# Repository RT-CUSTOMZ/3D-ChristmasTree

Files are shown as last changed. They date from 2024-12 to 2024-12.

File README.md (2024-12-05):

A 3D Christmas Tree based on WLED
USE WS2812 or SK6812 LEDs in combination with an WaveShare ESP32-S3 Mini Development Board
https://eckstein-shop.de/WaveShare-ESP32-S3-Mini-Development-Board-ESP32-S3FH4R2-240MHz-24GHz-Wi-Fi-Bluetooth-5

Board thickness 1.6 mm
Can use HASL or chem. Gold plating for silver or gold colored christmas ornaments

Populate boards accoring to silk screen prints
Connectors belong to the side with the silk screen print
Check LED function before assambling the tree
Slide the two tree PCBs into each other and use symbols on PCBs to ensure correct orientation
Afterwards use the same symbols as solder joints to give the tree more stability
Lastely connect the brain PCB to the tree assembly

As of end 2024 the WLED software is marked experimental for ESP32-S3 chipset, therefore install WLED via 
https://wled-install.github.io/
and select an ESP32-S3 version (4 MB Flash).

After installation open WLED controls and load Presets and Configuration from Backup Files

Short button press - On / Off
Long button press - Toggle presets

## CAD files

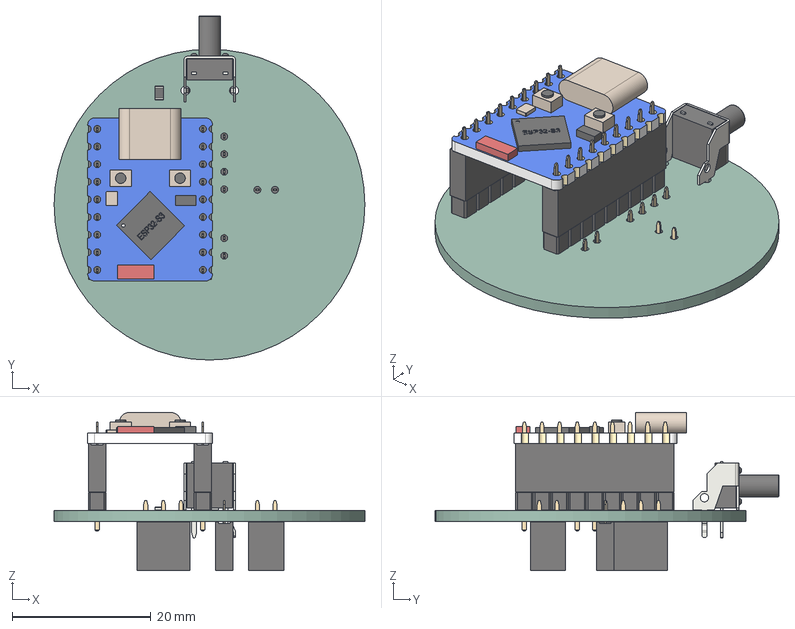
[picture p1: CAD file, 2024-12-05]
ChristmasTreeBrain/ChristmasTreeBrain/ChristmasTreeBrain.step
44.8 x 49.6 x 22.8 mm
SW_Tactile_SPST_Angled_PTS645Vx83-2LFS
ESP32-S3 Zero
PinHeader_1x09_P254mm_Vertical x 2
PinSocket_1x09_P254mm_Vertical x 2
R_0805_2012Metric
PinSocket_1x04_P254mm_Vertical
PinSocket_1x03_P254mm_Vertical
PinSocket_1x02_P254mm_Vertical x 2
ChristmasTreeBrain_PCB

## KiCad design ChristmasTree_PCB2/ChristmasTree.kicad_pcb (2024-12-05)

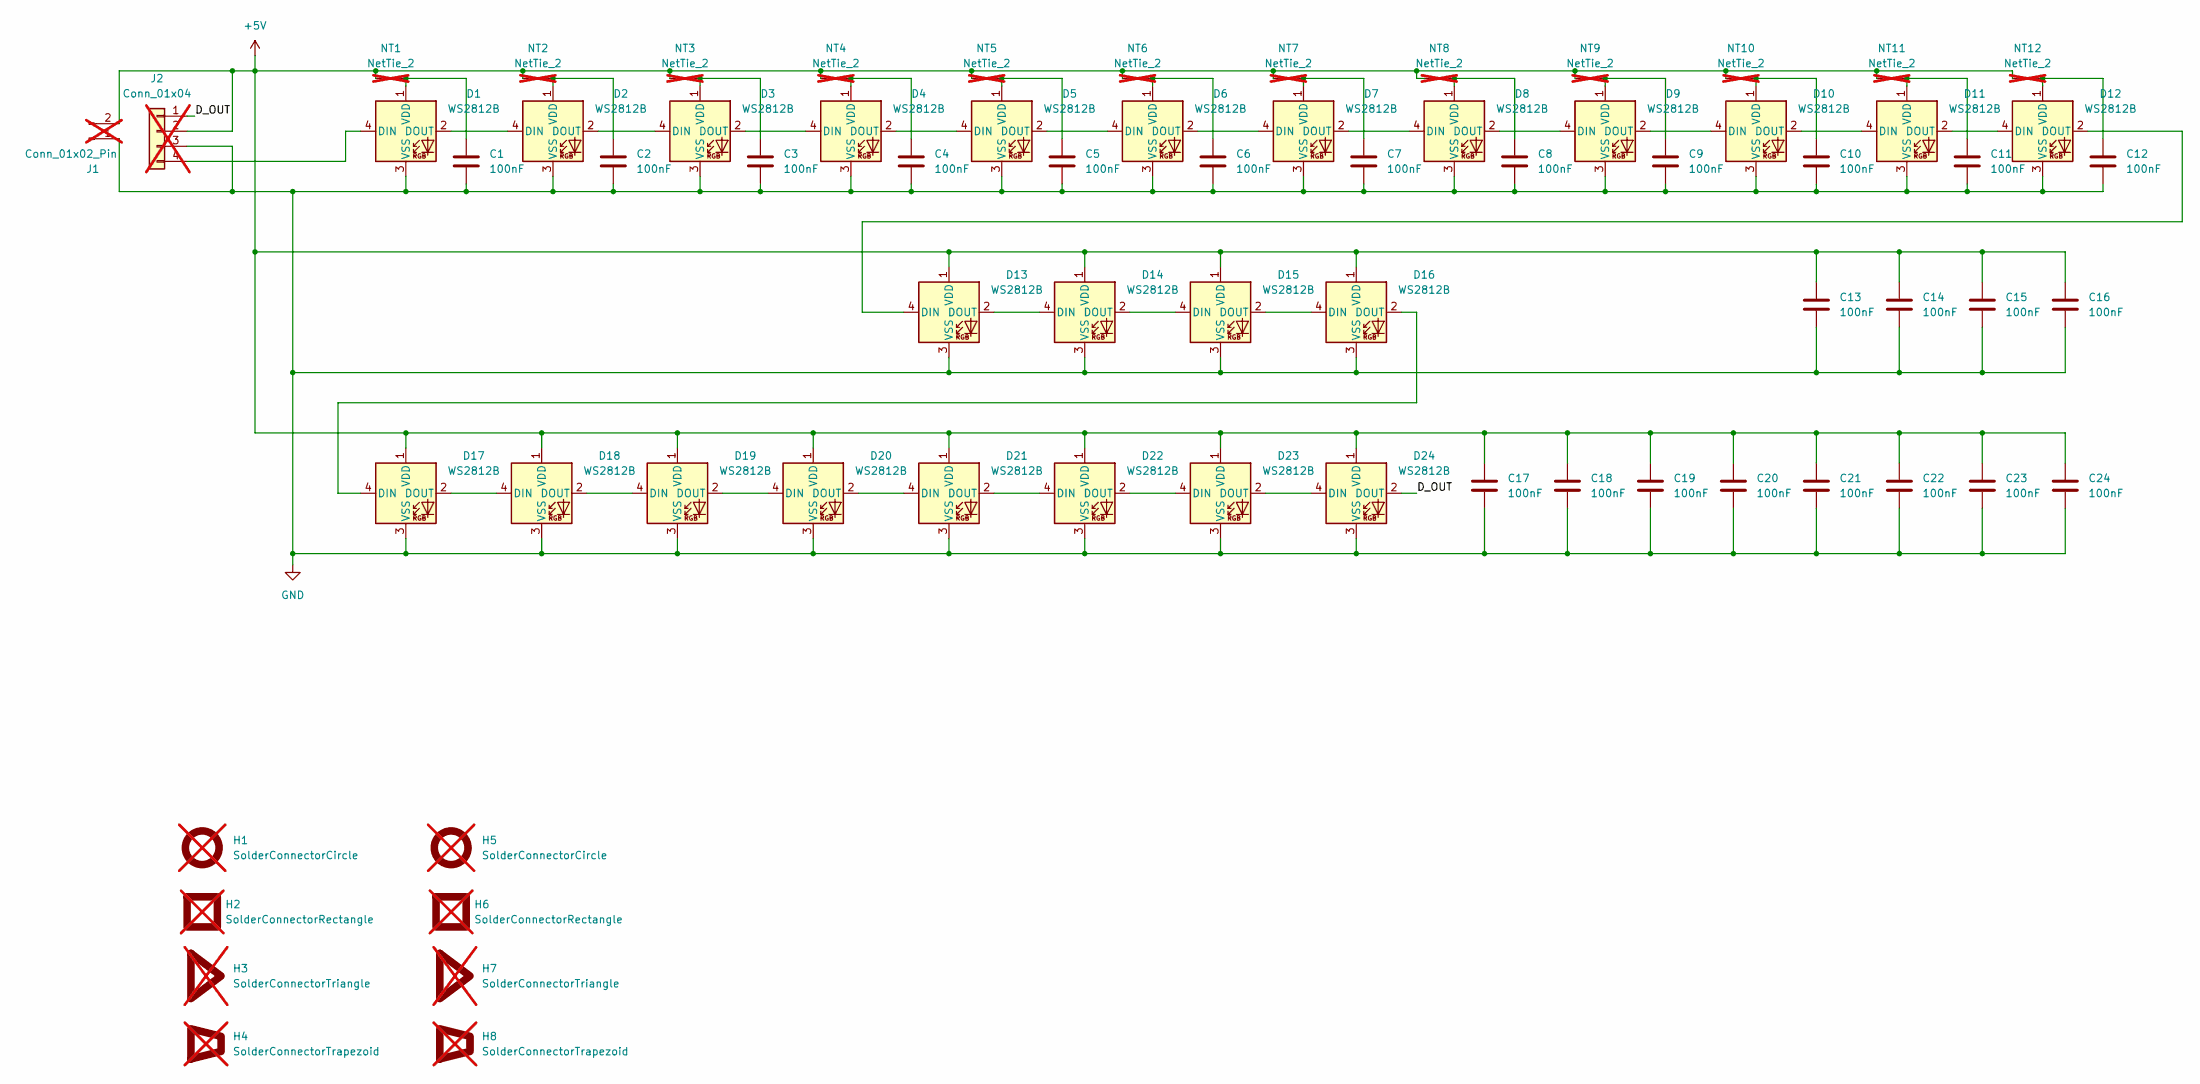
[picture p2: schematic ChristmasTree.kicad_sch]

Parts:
C1, C2, C3, C4, C5, C6, C7, C8, C9, C10, C11, C12, C13, C14, C15, C16, C17, C18, C19, C20, C21, C22, C23, C24: 100nF; C_0805_2012Metric_Pad1.18x1.45mm_HandSolder; LCSC C396718
D1, D2, D3, D4, D5, D6, D7, D8, D9, D10, D11, D12: WS2812B; LED_WS2812B_PLCC4_ECO1; LCSC C5378724
D13, D14, D15, D16, D17, D18, D19, D20, D21, D22, D23, D24: WS2812B; LED_WS2812B_ECO2; LCSC C5378724
H1, H5: SolderConnectorCircle; not fitted
H2, H6: SolderConnectorRectangle; not fitted
H3, H7: SolderConnectorTriangle; not fitted
H4, H8: SolderConnectorTrapezoid; not fitted
J1: Conn_01x02_Pin; PinHeader_1x02_P2.54mm_Horizontal; not fitted
J2: Conn_01x04; PinHeader_1x04_P2.54mm_Horizontal; not fitted
NT1, NT2, NT3, NT4, NT5, NT6, NT7, NT8, NT9, NT10, NT11, NT12: NetTie_2; NetTie-2_SMD_Pad0.5mm; not fitted

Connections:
+5V: C13.1, C14.1, C15.1, C16.1, C17.1, C18.1, C19.1, C20.1, C21.1, C22.1, C23.1, C24.1, D13.1 (VDD), D14.1 (VDD), D15.1 (VDD), D16.1 (VDD), D17.1 (VDD), D18.1 (VDD), D19.1 (VDD), D20.1 (VDD), D21.1 (VDD), D22.1 (VDD), D23.1 (VDD), D24.1 (VDD), J1.2, J2.2, NT1.1, NT2.1, NT3.1, NT4.1, NT5.1, NT6.1, NT7.1, NT8.1, NT9.1, NT10.1, NT11.1, NT12.1
/D_OUT: D24.2 (DOUT), J2.1
GND: C1.2, C2.2, C3.2, C4.2, C5.2, C6.2, C7.2, C8.2, C9.2, C10.2, C11.2, C12.2, C13.2, C14.2, C15.2, C16.2, C17.2, C18.2, C19.2, C20.2, C21.2, C22.2, C23.2, C24.2, D1.3 (VSS), D2.3 (VSS), D3.3 (VSS), D4.3 (VSS), D5.3 (VSS), D6.3 (VSS), D7.3 (VSS), D8.3 (VSS), D9.3 (VSS), D10.3 (VSS), D11.3 (VSS), D12.3 (VSS), D13.3 (VSS), D14.3 (VSS), D15.3 (VSS), D16.3 (VSS), D17.3 (VSS), D18.3 (VSS), D19.3 (VSS), D20.3 (VSS), D21.3 (VSS), D22.3 (VSS), D23.3 (VSS), D24.3 (VSS), J1.1, J2.3
unnamed: D1.4 (DIN), J2.4
unnamed: D1.2 (DOUT), D2.4 (DIN)
unnamed: C1.1, D1.1 (VDD), NT1.2
unnamed: D2.2 (DOUT), D3.4 (DIN)
unnamed: C2.1, D2.1 (VDD), NT2.2
unnamed: D3.2 (DOUT), D4.4 (DIN)
unnamed: C3.1, D3.1 (VDD), NT3.2
unnamed: D4.2 (DOUT), D5.4 (DIN)
unnamed: C4.1, D4.1 (VDD), NT4.2
unnamed: D5.2 (DOUT), D6.4 (DIN)
unnamed: C5.1, D5.1 (VDD), NT5.2
unnamed: D6.2 (DOUT), D7.4 (DIN)
unnamed: C6.1, D6.1 (VDD), NT6.2
unnamed: D7.2 (DOUT), D8.4 (DIN)
unnamed: C7.1, D7.1 (VDD), NT7.2
unnamed: D8.2 (DOUT), D9.4 (DIN)
unnamed: C8.1, D8.1 (VDD), NT8.2
unnamed: C9.1, D9.1 (VDD), NT9.2
unnamed: D9.2 (DOUT), D10.4 (DIN)
unnamed: D10.2 (DOUT), D11.4 (DIN)
unnamed: C10.1, D10.1 (VDD), NT10.2
unnamed: D11.2 (DOUT), D12.4 (DIN)
unnamed: C11.1, D11.1 (VDD), NT11.2
unnamed: D12.2 (DOUT), D13.4 (DIN)
unnamed: C12.1, D12.1 (VDD), NT12.2
unnamed: D13.2 (DOUT), D14.4 (DIN)
unnamed: D14.2 (DOUT), D15.4 (DIN)
unnamed: D15.2 (DOUT), D16.4 (DIN)
unnamed: D16.2 (DOUT), D17.4 (DIN)
unnamed: D17.2 (DOUT), D18.4 (DIN)
unnamed: D18.2 (DOUT), D19.4 (DIN)
unnamed: D19.2 (DOUT), D20.4 (DIN)
unnamed: D20.2 (DOUT), D21.4 (DIN)
unnamed: D21.2 (DOUT), D22.4 (DIN)
unnamed: D22.2 (DOUT), D23.4 (DIN)
unnamed: D23.2 (DOUT), D24.4 (DIN)

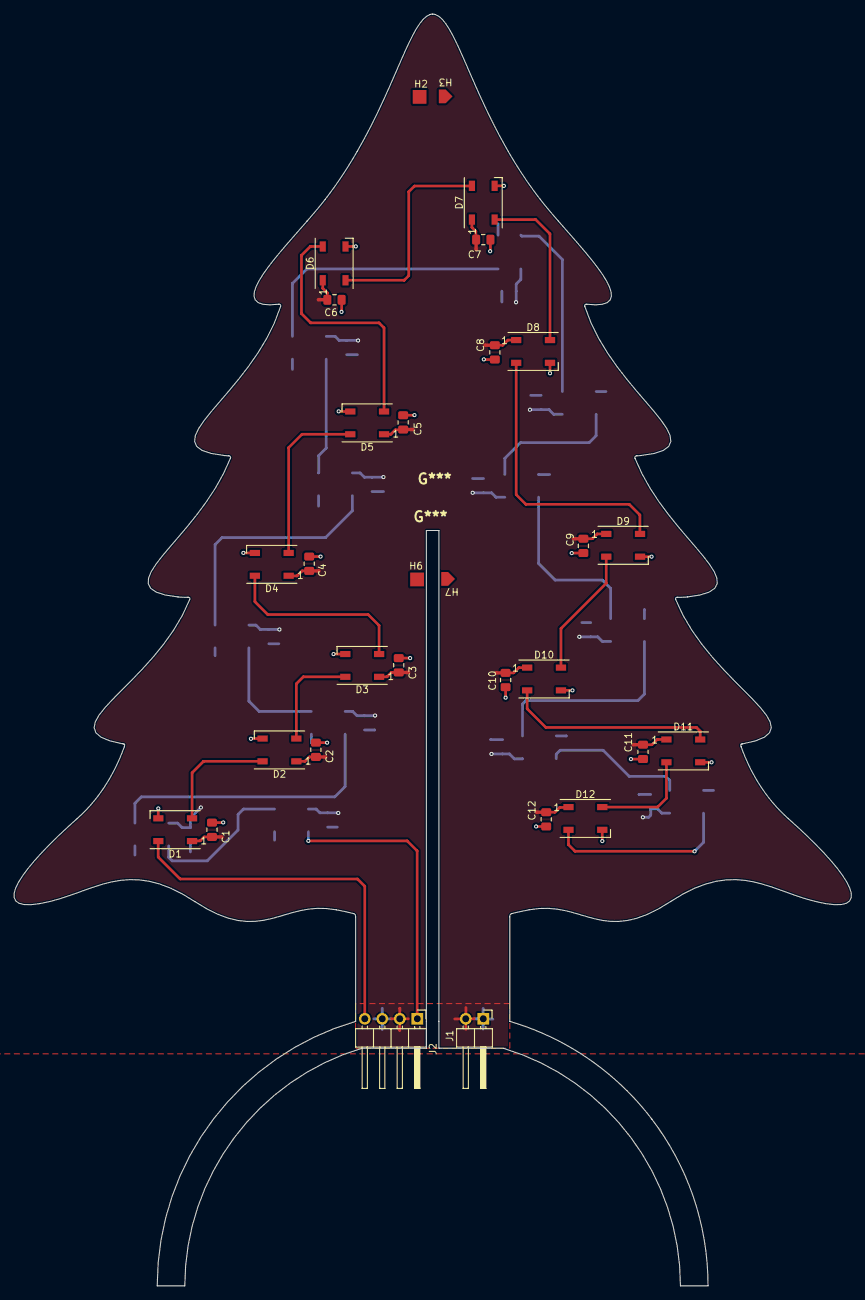
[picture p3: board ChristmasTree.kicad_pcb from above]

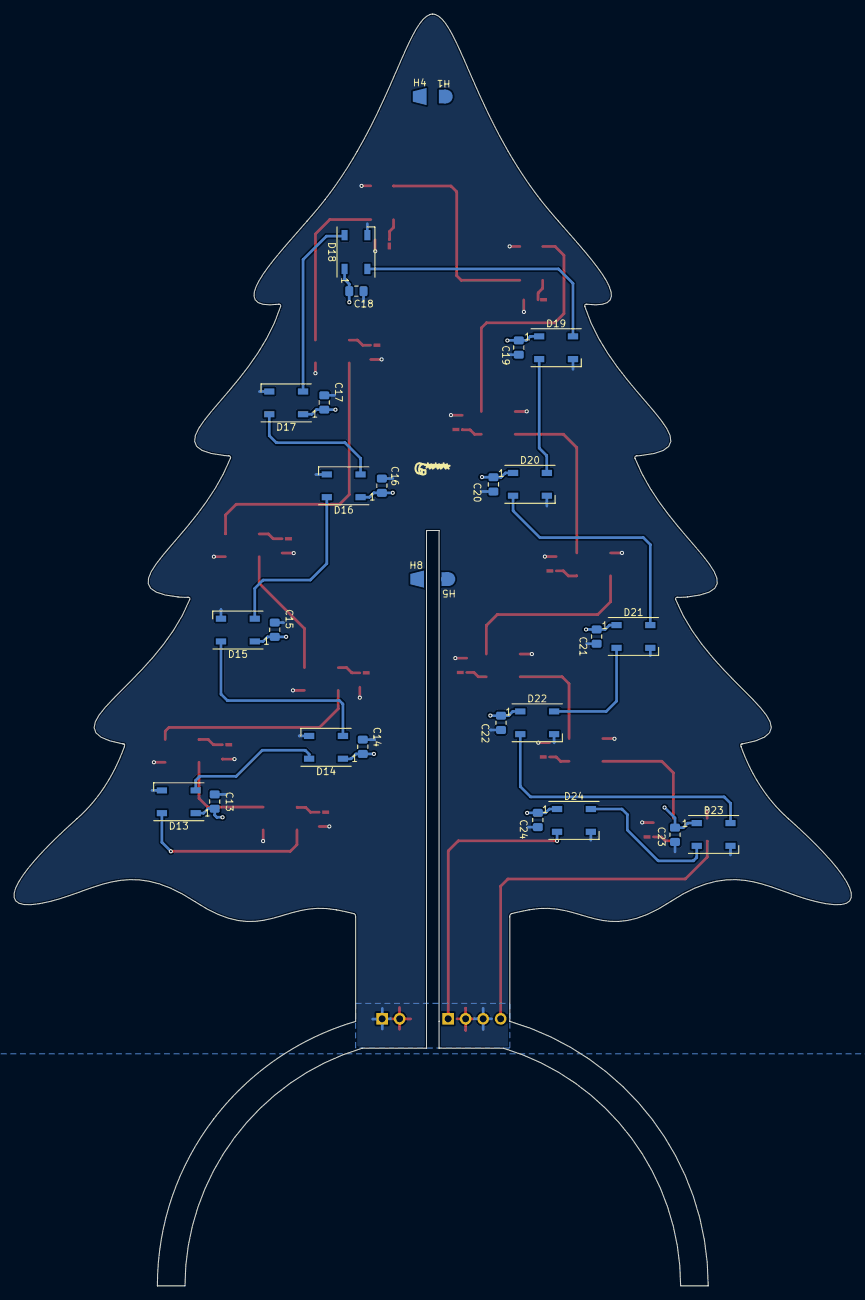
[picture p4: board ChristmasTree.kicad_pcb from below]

Board: 2 copper layers, 121.4 x 184.5 mm, 70 parts (28 on the bottom side), 39 nets.

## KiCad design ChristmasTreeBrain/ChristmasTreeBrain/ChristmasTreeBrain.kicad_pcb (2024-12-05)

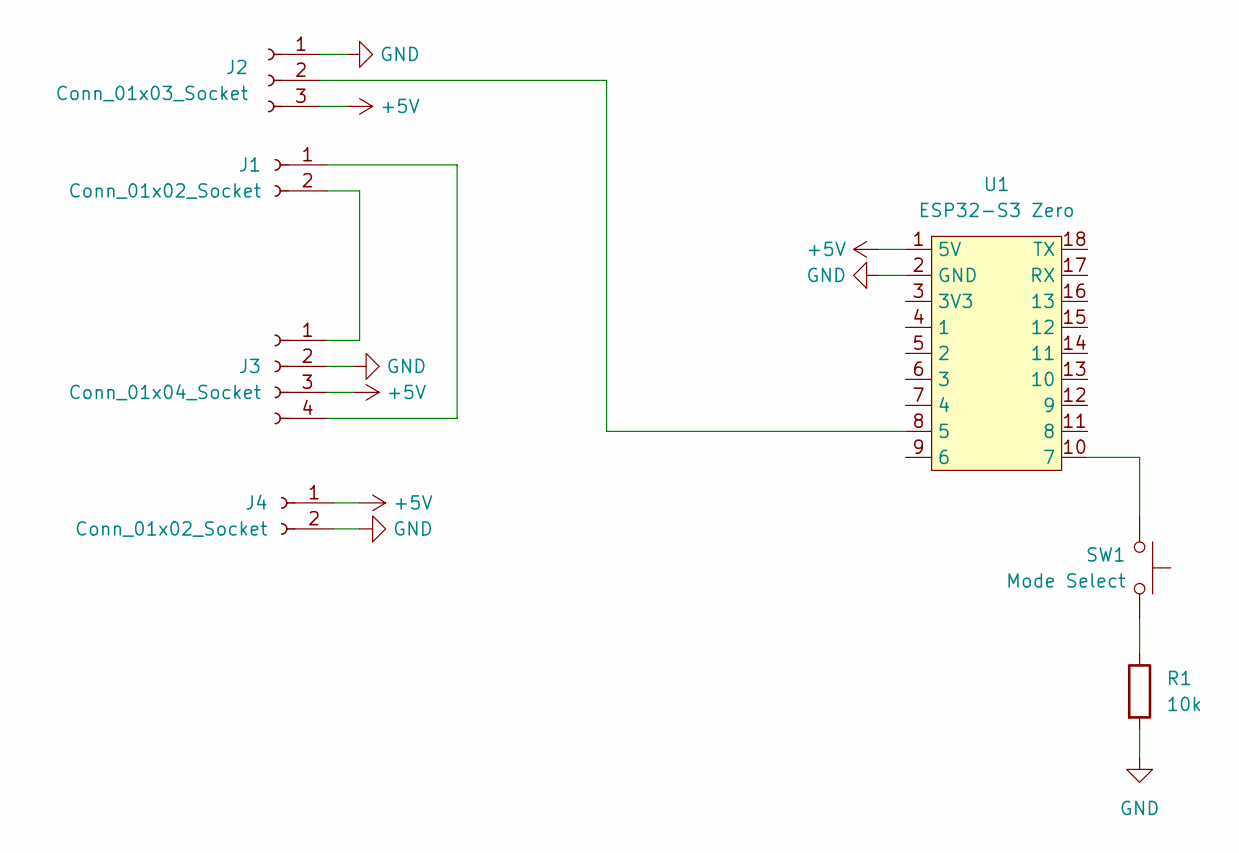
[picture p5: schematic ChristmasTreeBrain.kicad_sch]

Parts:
J1, J4: Conn_01x02_Socket; PinSocket_1x02_P2.54mm_Vertical
J2: Conn_01x03_Socket; PinSocket_1x03_P2.54mm_Vertical
J3: Conn_01x04_Socket; PinSocket_1x04_P2.54mm_Vertical
R1: 10k; R_0805_2012Metric
SW1: Mode Select; SW_Tactile_SPST_Angled_PTS645Vx83-2LFS
U1: ESP32-S3 Zero; ESP32-S3 Mini

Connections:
+5V: J2.3, J3.3, J4.1, U1.1 (5V)
GND: J2.1, J3.2, J4.2, R1.2, U1.2 (GND)
unnamed: J1.1, J3.4
unnamed: J1.2, J3.1
unnamed: J2.2, U1.8 (5)
unnamed: R1.1, SW1.1
unnamed: SW1.2, U1.10 (7)

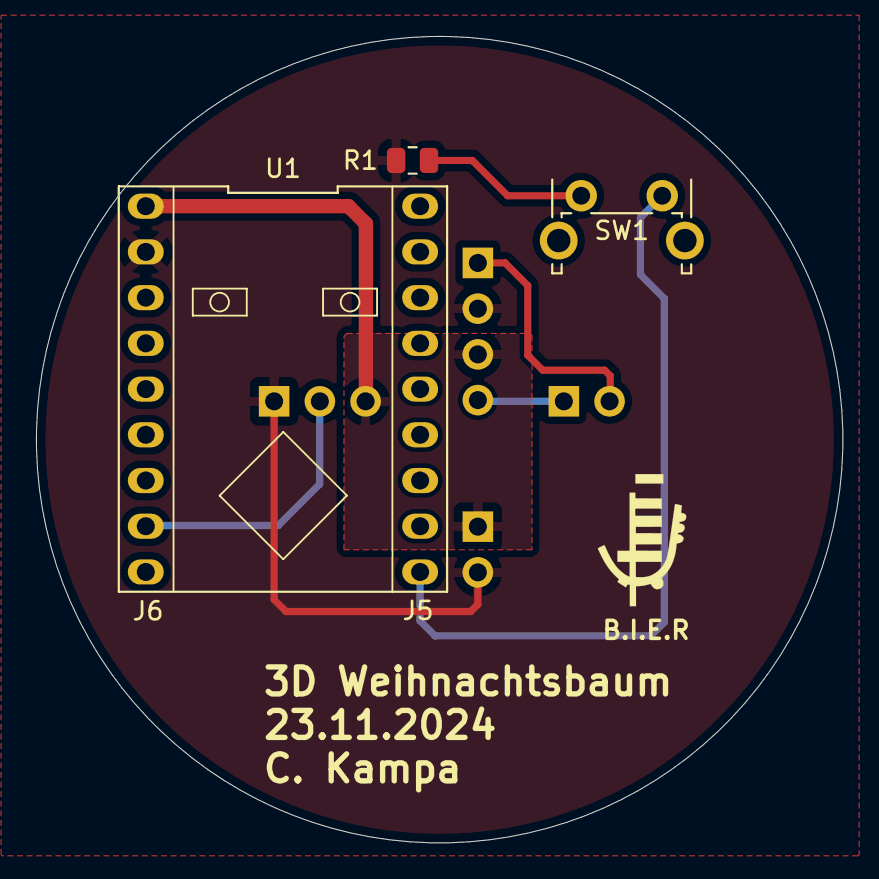
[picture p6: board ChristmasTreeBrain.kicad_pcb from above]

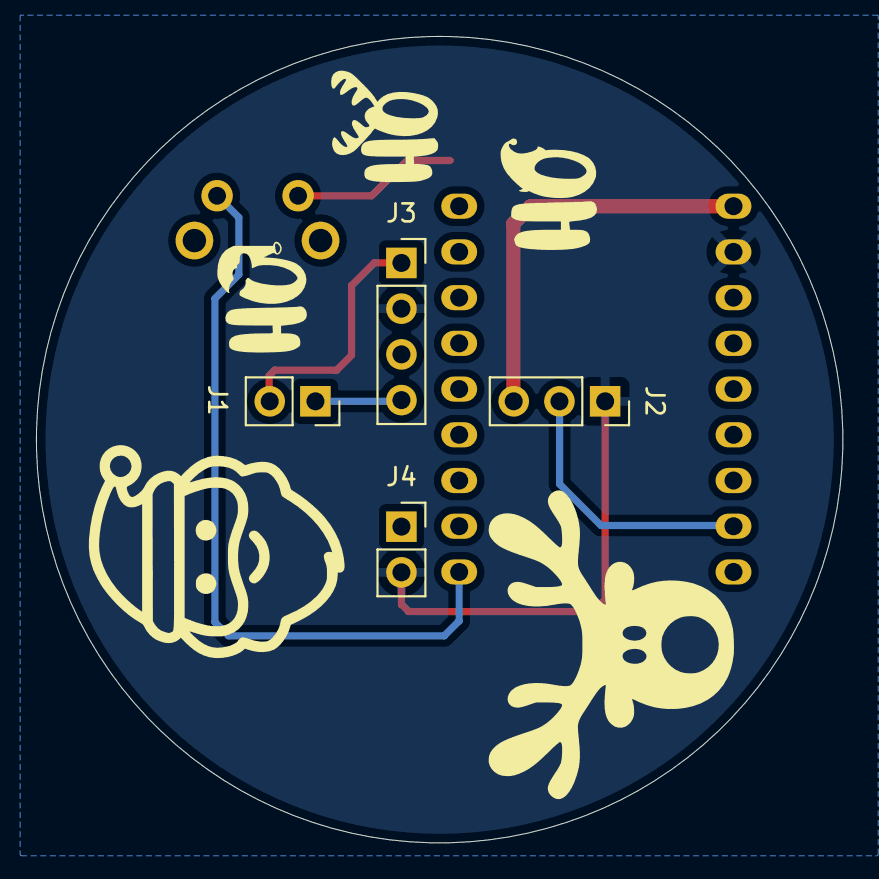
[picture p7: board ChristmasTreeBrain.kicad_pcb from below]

Board: 2 copper layers, 44.8 x 44.8 mm, 7 parts (4 on the bottom side), 7 nets.

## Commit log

2024-12-05 V1 für Wichteln 2024
    [ChristmasTree-B_Cu.gbl, ChristmasTree-B_Mask.gbs, ChristmasTree-B_Paste.gbp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]
2024-12-05 Footprints used for special silk screen prints
